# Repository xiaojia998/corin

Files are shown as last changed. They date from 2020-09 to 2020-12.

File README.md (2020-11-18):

# Corin

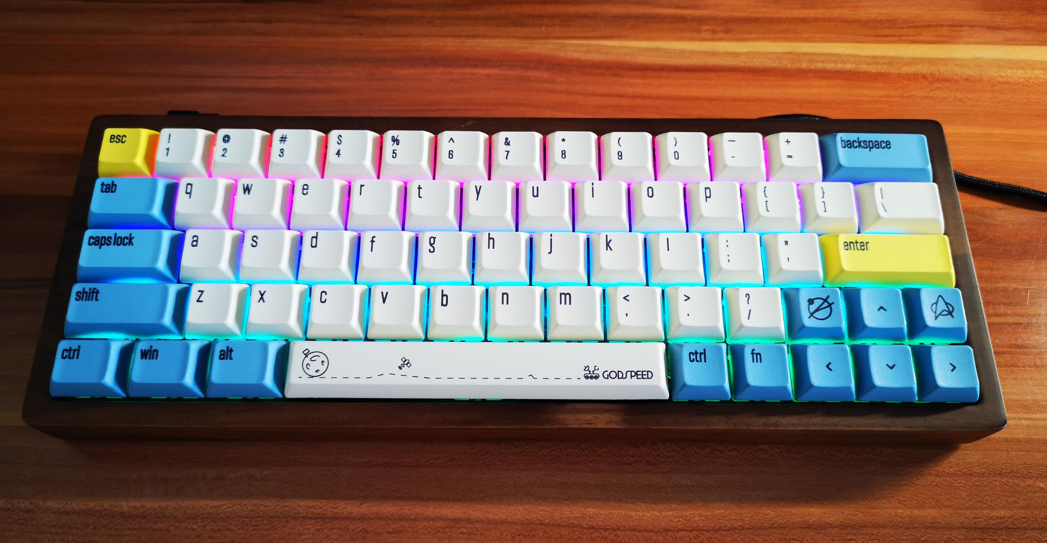
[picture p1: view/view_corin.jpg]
Corin view


## Introduction

Corin is a 64-key keyboard that adds 4 more arrow keys than a regular 60% keyboard, and has Home and End buttons next to the arrow keys. The laminated LEDs provide a great visual experience and this is the best keyboard for software development engineers (and maintenance engineers as well)!

The PCB is powered by a ATMEGA32U4-AU and is QMK compatible.

Use WS2812-3528 for LEDs on the PCB, which can be configured as per the QMK capabilities.

## Graphics

Corin bottom

Corin top

## Layouts

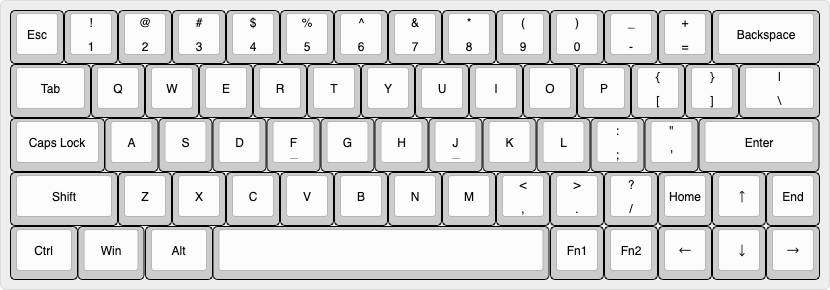
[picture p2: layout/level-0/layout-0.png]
layout-0


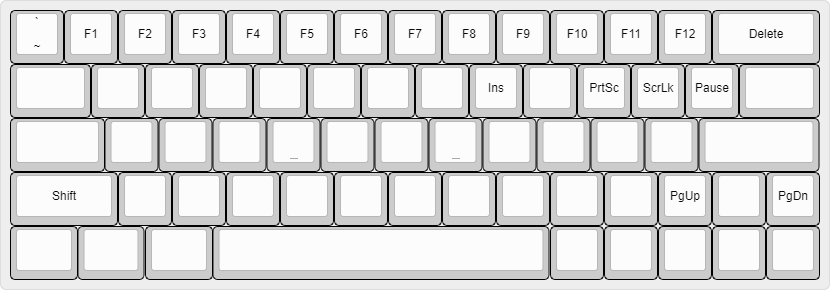
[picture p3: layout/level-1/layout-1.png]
layout-1


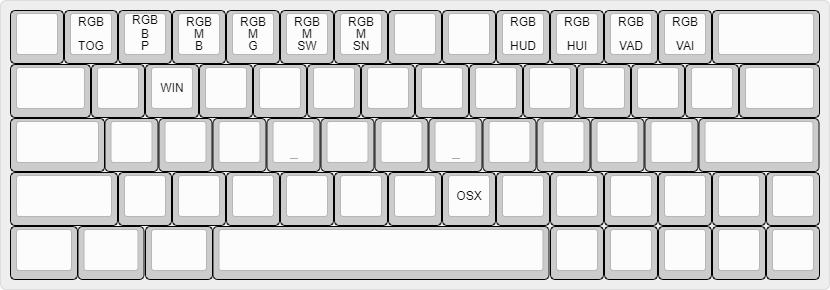
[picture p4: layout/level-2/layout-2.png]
layout-2


## Logo

The Longnald logo was designed using the Deceptibots font by [Iconian Fonts](http://www.iconian.com/index.html). The Longnald logo is therefore intellectual and commercial property of [Seaton Jiang](https://github.com/seatonjiang), the Deceptibots font is property of Iconian Fonts and their owners.

## License

This project is released under the GNU General Public License v3.0. For the license, please refer to the LICENCE file.

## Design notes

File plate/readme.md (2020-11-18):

## Plate layout

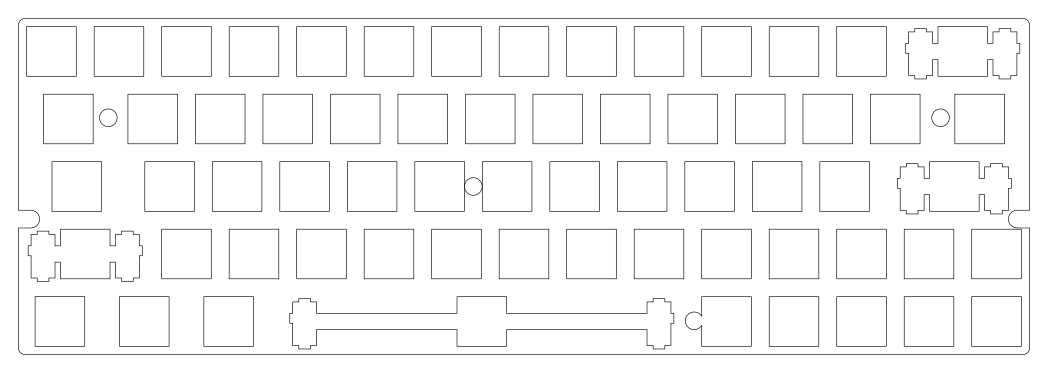
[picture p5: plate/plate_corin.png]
plate


## Satellite axis

| Specification | Quantity |
| --- | --- |
| 6.25U | 1 |
| 2U | 3 |

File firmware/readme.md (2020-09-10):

## About Firmware

Keyboard Name: Corin

Keyboard Maintainer: [Longnald](https://github.com/longnald) & [Seaton Jiang](https://github.com/seatonjiang)

Hardware Supported: [Corin PCB (uses 32U4)](https://github.com/longnald/corin)

## Build Firmware

Install QMK and QMK Toolbox, execute the following command to compile:

```shell
make longnald/corin:default
```

See [build environment setup](https://docs.qmk.fm/#/getting_started_build_tools) then the [make instructions](https://docs.qmk.fm/#/getting_started_make_guide) for more information.

## Flashing Keyboard

### Put Your Keyboard into DFU (Bootloader) Mode

Press the physical RESET button. In order to flash your custom firmware you must first put your keyboard into a special flashing mode. While it is in this mode you will not be able to type or otherwise use your keyboard. It is very important that you do not unplug the keyboard or otherwise interrupt the flashing process while the firmware is being written.

Then you should see a message in yellow, similar to this in QMK Toolbox:

```shell
*** DFU device connected: Atmel Corp. ATmega32U4 (03EB:2FF4:0000)
```

### Flashing Your Keyboard with QMK Toolbox

The simplest way to flash your keyboard will be with the [QMK Toolbox](https://github.com/qmk/qmk_toolbox/releases).

See [Flashing Your Keyboard with QMK Toolbox](https://docs.qmk.fm/#/newbs_flashing) for more information.

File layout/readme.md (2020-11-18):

## Keycap size

| Specification | Quantity |
| --- | --- |
| 1U | 54 |
| 1.25U | 3 |
| 1.5U | 2 |
| 1.75U | 1 |
| 2U | 2 |
| 2.25U | 1 |
| 6.25U | 1 |

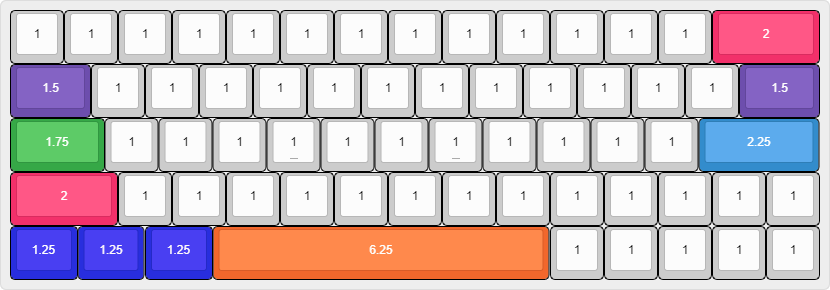
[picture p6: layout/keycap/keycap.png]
keycap


## Keyboard layout

### First layer layout

layout-0

### Second layer layout

layout-1

### Third layer layout

layout-2

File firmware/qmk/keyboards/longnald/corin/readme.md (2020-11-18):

# Corin

Corin view

Corin is a 64-key keyboard that adds 4 more arrow keys than a regular 60% keyboard made and sold by Seaton Jiang.

- Keyboard Maintainer: [Longnald](https://github.com/longnald) & [Seaton Jiang](https://github.com/seatonjiang)
- Hardware Supported: [Corin PCB (uses 32U4)](https://github.com/longnald/corin)
- Hardware Availability: [www.longnald.com](https://www.longnald.com/)

Make example for this keyboard (after setting up your build environment):

    make longnald/corin:default

See [build environment setup](https://docs.qmk.fm/#/getting_started_build_tools) then the [make instructions](https://docs.qmk.fm/#/getting_started_make_guide) for more information.

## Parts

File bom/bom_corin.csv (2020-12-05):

ID | Name | Designator | Footprint | Quantity | Manufacturer Part | Manufacturer | Supplier | Supplier Part
1 | 100nF | C69,C70,C71,C72 | C0805 | 4 | CC0805KRX7R9BB104 | YAGEO | LCSC | C49678
2 | 5.1KΩ | R5,R6 | R0805 | 2 | CR-05JL7---5K1 | Viking Tech | LCSC | C416158
3 | 10KΩ | R1,R2 | R0603 | 2 | 0603WAD1002T5E | Uniroyal Elec | LCSC | C167144
4 | 1N4148 | D1,D2,D3,D4,D5,D6,D7,D8,D9,D10,D11,D12,D13,D14,D15,D16,D17,D18,D19,D20,D21,D22,D23,D24,D25,D26,D27,D28,D29,D30,D31,D32,D33,D34,D35,D36,D37,D38,D39,D40,D41,D42,D43,D44,D45,D46,D47,D48,D49,D50,D51,D52,D53,D54,D55,D56,D57,D58,D59,D60,D61,D62,D63,D64 | SOD-123_L2.8-W1.8-LS3.7-RD | 64 | 1N4148W | Jingdao | LCSC | C115103
5 | 16MHz | X1 | OSC-SMD_2P-L5.0-W3.2 | 1 | XSHEELNANF-16MHZ | TAITIEN Elec | LCSC | C242221
6 | 22Ω | R3,R4 | R0603 | 2 | 0603WAF220JT5E | UniOhm | LCSC | C23345
7 | 100nF | C1,C2,C3,C4,C5,C6,C7,C8,C9,C10,C11,C12,C13,C14,C15,C16,C17,C18,C19,C20,C21,C22,C23,C24,C25,C26,C27,C28,C29,C30,C31,C32,C33,C34,C35,C36,C37,C38,C39,C40,C41,C42,C43,C44,C45,C46,C47,C48,C49,C50,C51,C52,C53,C54,C55,C56,C57,C58,C59,C60,C61,C62,C63,C64 | C0603 | 64 | CC0603KRX7R9BB104 | YAGEO | LCSC | C14663
8 | PRTR5V0U2X | E1 | SOT-143_L2.9-W1.3-P1.92-LS2.3-BL | 1 | PRTR5V0U2X | Yenji Elec | LCSC | C12333
9 | 22pF | C65,C66 | C0603 | 2 | CL10C220JB81PNC | SAMSUNG | LCSC | C170132
10 | TS-1088R-02026 | SW1 | SW-SMD_L3.9-W3.0-P4.45 | 1 | TS-1088R-02026 | XUNPU | LCSC | C455280
11 | 1uF | C67,C68 | C0603 | 2 | CL10A105KB8NNNC | SAMSUNG | LCSC | C15849
12 | ATMEGA32U4-AU | IC1 | QFP-44_L10.0-W10.0-P0.80-LS13.2-BL | 1 | ATMEGA32U4-AU | MICROCHIP | LCSC | C44854
13 | TYPE-C | USB1 | USB-C-SMD_TYPE-C16PIN | 1 | TYPE-C16PIN | SHOU HAN | LCSC | C393939
14 | WS2812B | LED1,LED2,LED3,LED4,LED5,LED6,LED7,LED8,LED9,LED10,LED11,LED12,LED13,LED14,LED15,LED16,LED17,LED18,LED19,LED20,LED21,LED22,LED23,LED24,LED25,LED26,LED27,LED28,LED29,LED30,LED31,LED32,LED33,LED34,LED35,LED36,LED37,LED38,LED39,LED40,LED41,LED42,LED43,LED44,LED45,LED46,LED47,LED48,LED49,LED50,LED51,LED52,LED53,LED54,LED55,LED56,LED57,LED58,LED59,LED60,LED61,LED62,LED63,LED64 | WS2812-3528 | 64
15 | Cherry MX | S1,S2,S3,S4,S5,S6,S7,S8,S9,S10,S11,S12,S13,S14,S15,S16,S17,S18,S19,S20,S21,S22,S23,S24,S25,S26,S27,S28,S29,S30,S31,S32,S33,S34,S35,S36,S37,S38,S39,S40,S41,S42,S43,S44,S45,S46,S47,S48,S49,S50,S51,S52,S53,S54,S55,S56,S57,S58,S59,S60,S61,S62,S63,S64 | CHERRY-MX-RGB | 64

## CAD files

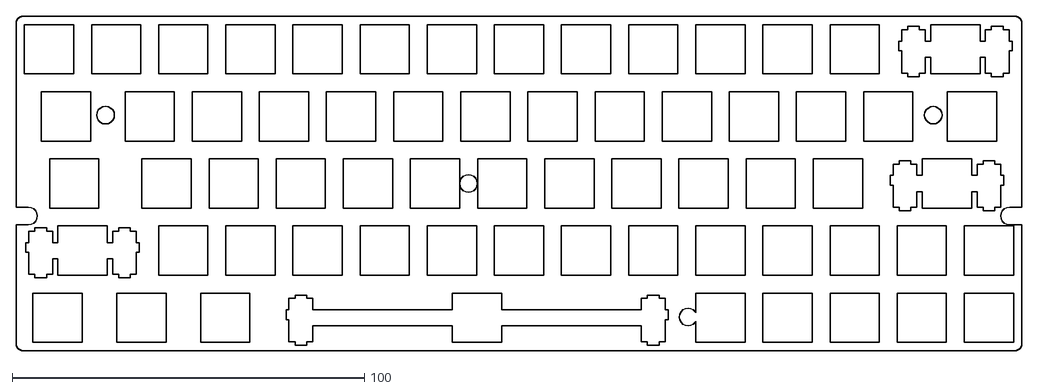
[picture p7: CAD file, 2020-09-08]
plate/plate_corin.dxf
285.4 x 94.9

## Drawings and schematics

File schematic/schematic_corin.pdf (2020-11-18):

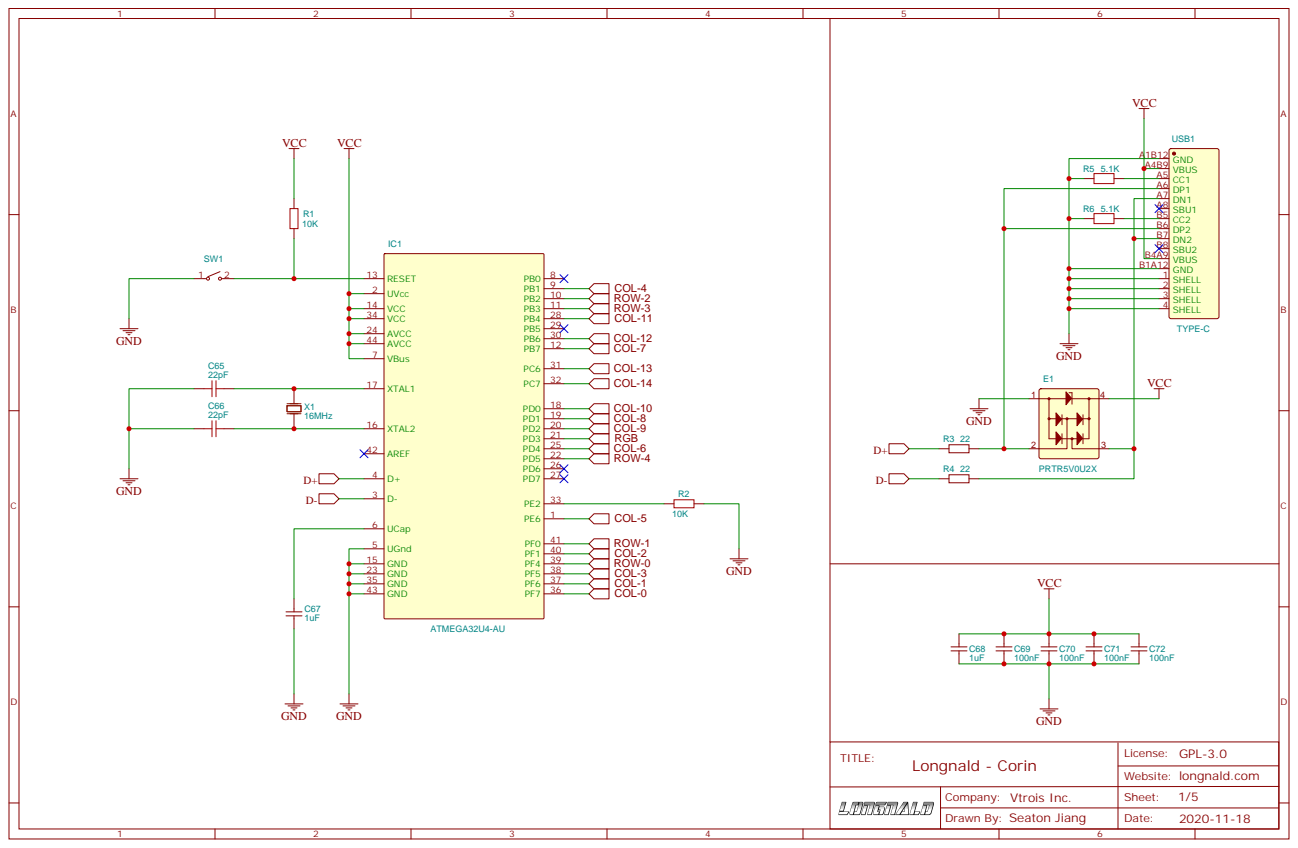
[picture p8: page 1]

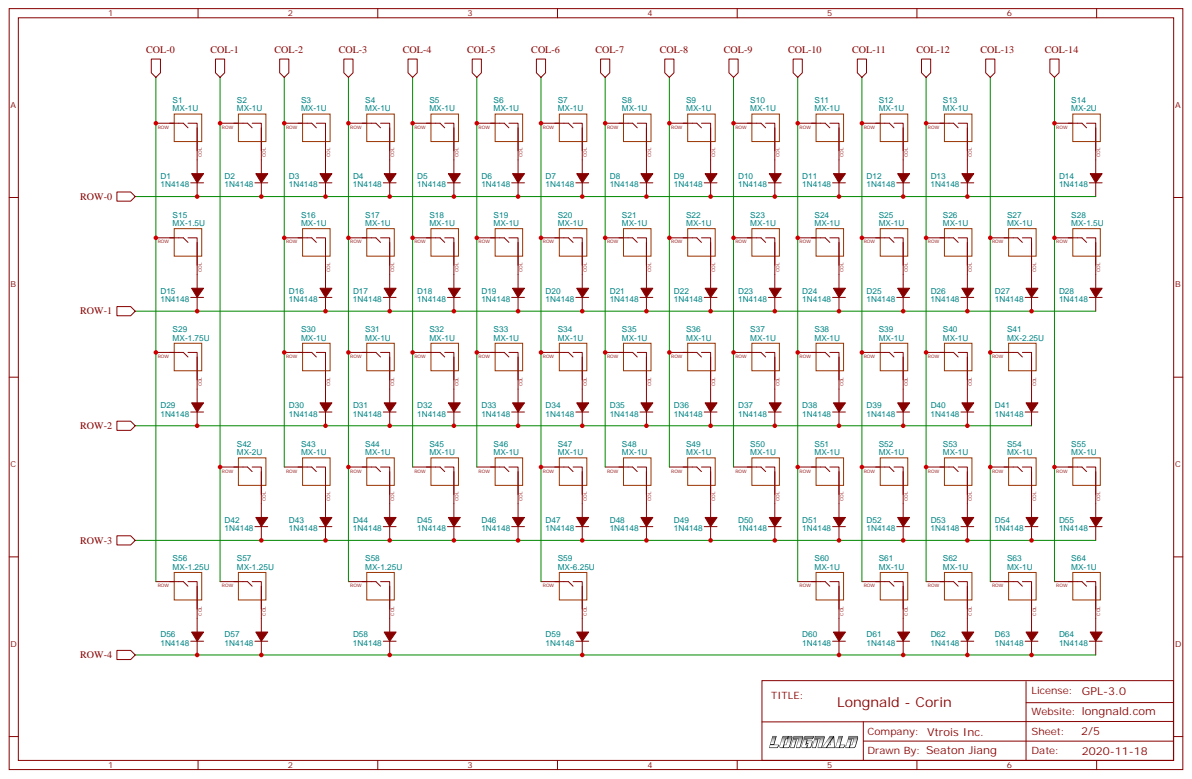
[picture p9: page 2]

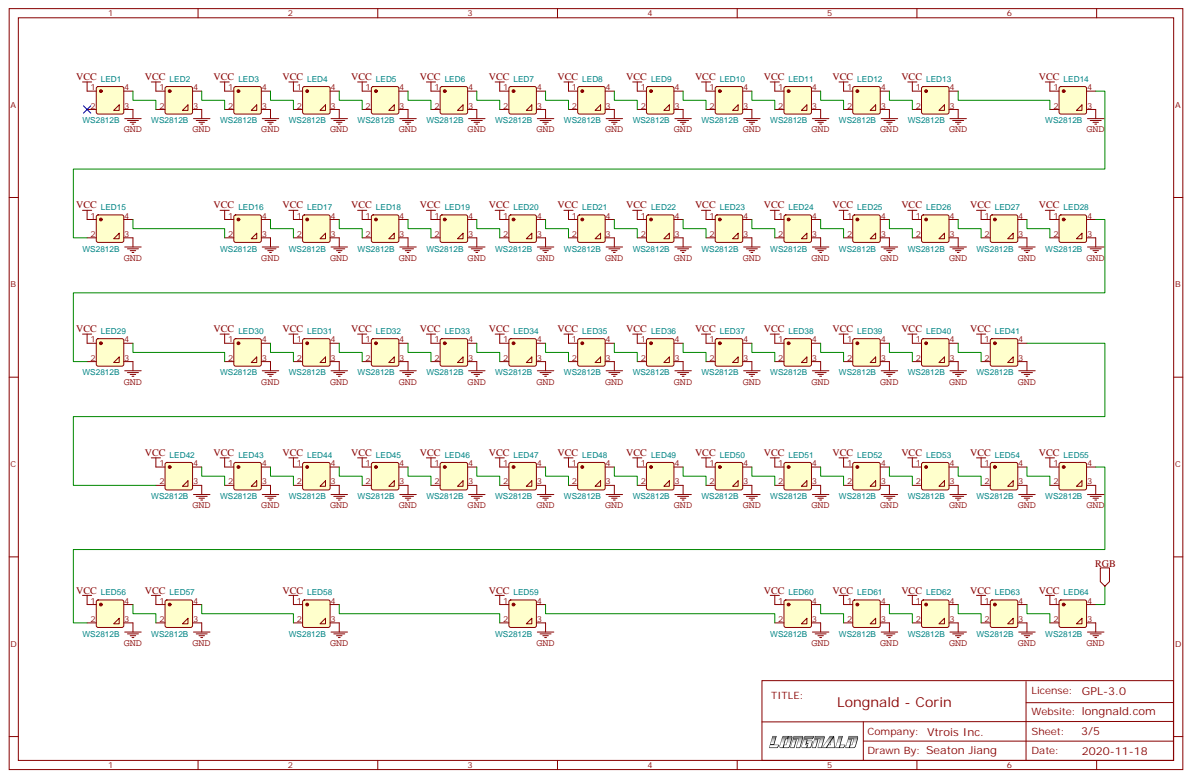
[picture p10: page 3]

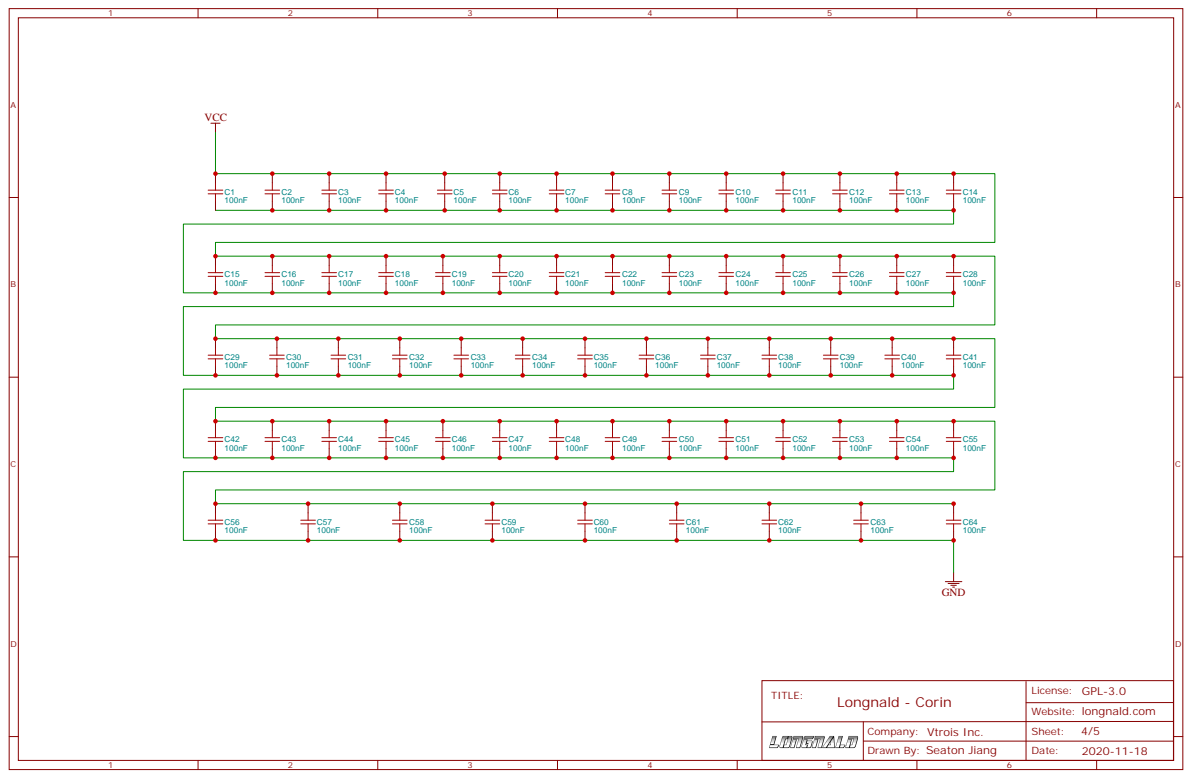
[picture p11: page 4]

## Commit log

2020-09-08 feat: add bom file
    [bom_corin_v1.0.csv]
2020-09-08 feat: add gerber files
    [Gerber_BoardOutline.GKO, Gerber_BottomLayer.GBL, Gerber_BottomPasteMaskLayer.GBP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]
2020-09-08 feat: add plate files
    [plate_corin_v1.0.dxf]
2020-09-08 feat: add schematic file
2020-09-08 fix: screen printing error
    [Gerber_BoardOutline.GKO, Gerber_BottomLayer.GBL, Gerber_BottomPasteMaskLayer.GBP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]
2020-09-08 feat: change the fn button position
2020-09-10 chore: rename files
    [Gerber_BoardOutline.GKO, Gerber_BottomLayer.GBL, Gerber_BottomPasteMaskLayer.GBP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]
2020-09-10 feat: add plate readme file
2020-11-03 feat: add the pick and place
    [pick&place_corin.csv]
2020-11-03 feat: add the PCB design files
    [core_corin.schdoc, matrix_corin.schdoc, other_corin.schdoc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]
2020-11-18 feat: add optimize drawings and doc content
    [Gerber_BoardOutline.GKO, Gerber_BottomLayer.GBL, Gerber_BottomPasteMaskLayer.GBP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]
2020-12-05 feat: optimize table display
    [PickAndPlace_corin.csv]
